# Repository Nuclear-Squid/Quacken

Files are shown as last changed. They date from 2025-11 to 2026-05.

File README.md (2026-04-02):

# Quacken

Libre, ergonomic, *polymorphic*: a single PCB for many possible layouts.

[3×6, 3×5, hummingbird, and everything in between](https://html-preview.github.io/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).

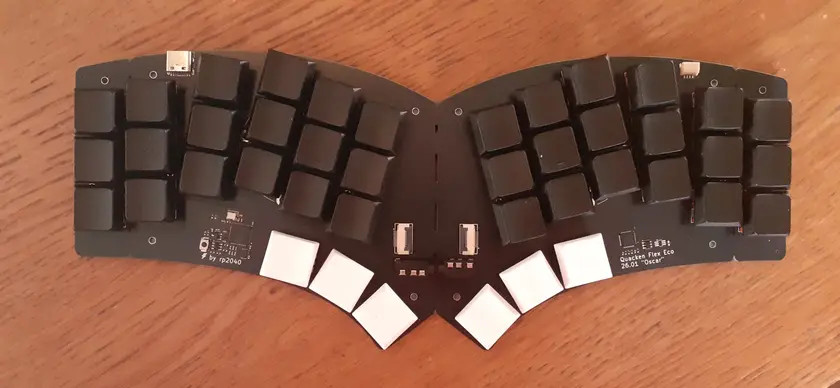
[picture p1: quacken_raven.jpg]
Quacken Flex, unibody Raven, 42 keys

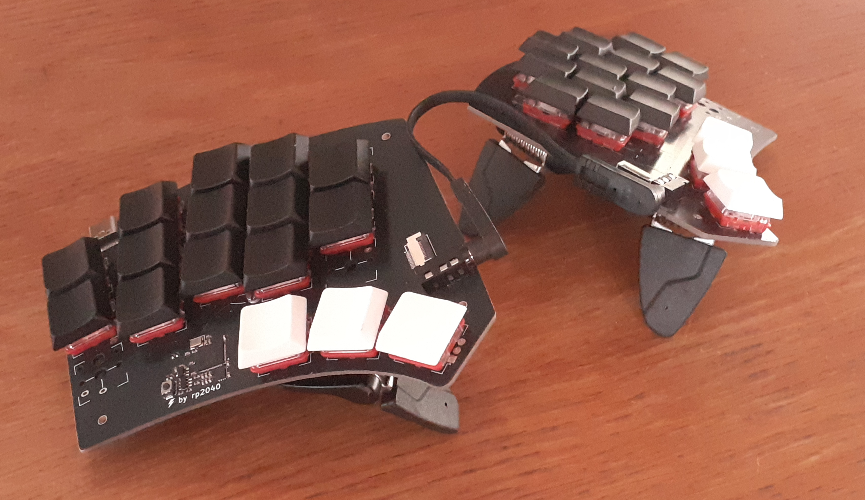
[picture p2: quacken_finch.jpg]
Quacken Flex, split Finch, 32 keys


## Roadmap

- [x] **Quacken Zero**: unibody
  - [x] first batch with a Pro Micro slot, to experiment geometry and design choices
  - [ ] next batches with an onboard nRF52840 (Bluetooth LE) and the updated geometry

- [x] **Quacken Flex**: unibody by default, splittable by choice
  - [x] onboard RP2040 (left) and I/O expander (right)
  - [x] splittable in two (I²C communication over a TRRS cable)
  - [x] splittable outer columns
  - [ ] hotswap sockets
  - [ ] optional Circle Trackpad
  - [x] optional rotary encoders

- [ ] **Marie-Quackenette**: split and wireless variant of the Quacken Flex.

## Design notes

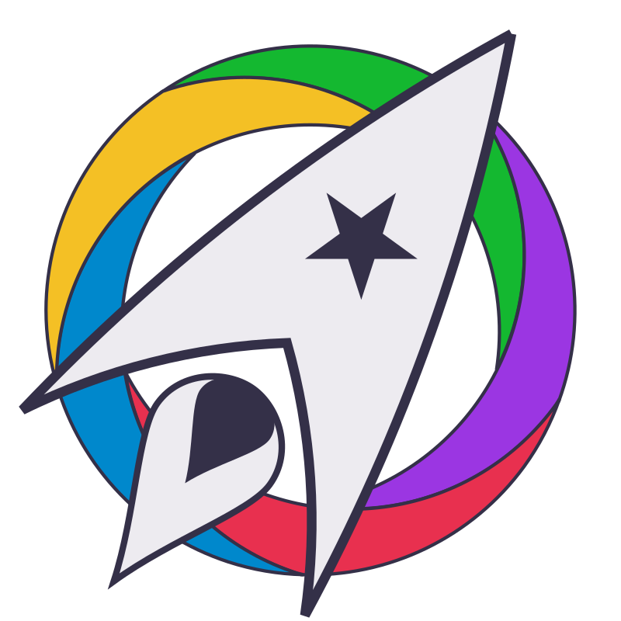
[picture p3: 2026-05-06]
flex/silkscreen/ergol.png

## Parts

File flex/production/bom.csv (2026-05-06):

Designator | Footprint | Quantity | Value | LCSC Part #
C1, C2 | 0402 | 2 | 15p | C1548
C10, C12, C13, C14, C16, C18, C19, C20, C3, C4, C7, C9 | 0402 | 12 | 100n | C1525
C15, C17, C5, C6, C8 | 0402 | 5 | 1u | C52923
J1, J2 | Cirque | 2 | CIRQUE_Left, CIRQUE_Right | C2911838
J3 | USB_C_Receptacle_HRO_TYPE-C-31-M-12 | 1 | USB_C_Receptacle_USB2.0_16P | C165948
J4 | JST_SH_SM04B-SRSS-TB_1x04-1MP_P1.00mm_Horizontal | 1 | Qwiic | C160404
R1, R5 | 0402 | 2 | 1k | C11702
R10, R9 | 0402 | 2 | 4.7k | C25900
R11, R2, R7, R8 | 0402 | 4 | 2.2k | C25879
R12, R13 | 0402 | 2 | 5.1k | C25905
R3, R4 | 0402 | 2 | 27 | C2909343
R6 | 0402 | 1 | 10k | C25744
TRRS1, TRRS2 | TRRS-PJ-320A-dual | 2 | AudioJack4 | C2884926
SMDSW1 | SW_SPST_TS-1088-xR020 | 1 | TS-1088R-02026 | C720477
U1 | Winbond_USON-8-1EP_3x2mm_P0.5mm_EP0.2x1.6mm | 1 | W25Q16JVUX | C2843335
U2 | QFN-56-1EP_7x7mm_P0.4mm_EP3.2x3.2mm | 1 | RP2040 | C2040
U3 | PCAL6524HEHZ | 1 | PCAL6524HEAZ | C3000497
U4 | SOT-23-3 | 1 | XC6206PxxxMR | C5446
U5, U6 | SOT-23-6 | 2 | SRV05-4 | C2836319
Y1 | Crystal_SMD_3225-4Pin_3.2x2.5mm | 1 | 12MHz 10pF | C91749

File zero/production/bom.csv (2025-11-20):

Designator | Footprint | Quantity | Value | LCSC Part #
D1, D10, D11, D12, D13, D14, D15, D16, D17, D18, D19, D2, D20, D21, D22, D23, D24, D25, D26, D27, D28, D29, D3, D30, D31, D32, D33, D34, D35, D36, D37, D38, D39, D4, D40, D41, D42, D5, D6, D7, D8, D9 | D_SOD-323 | 42

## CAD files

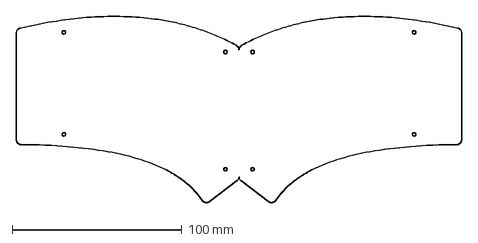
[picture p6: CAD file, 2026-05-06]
freecad/quacken_flex-Mono 3_6.dxf
262.0 x 109.6 mm

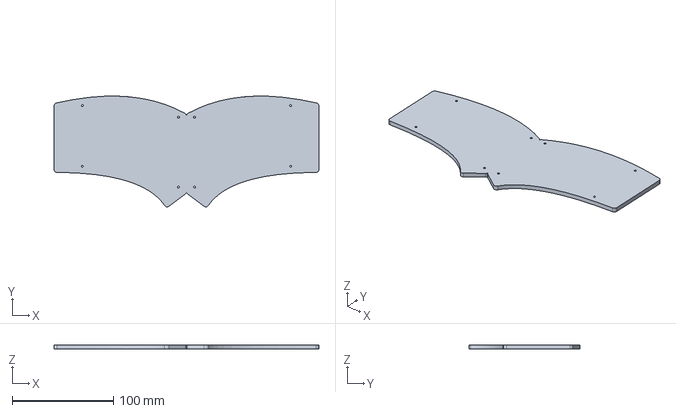
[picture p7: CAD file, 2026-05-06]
quacken_flex.FCStd
262.0 x 109.5 x 4.00 mm

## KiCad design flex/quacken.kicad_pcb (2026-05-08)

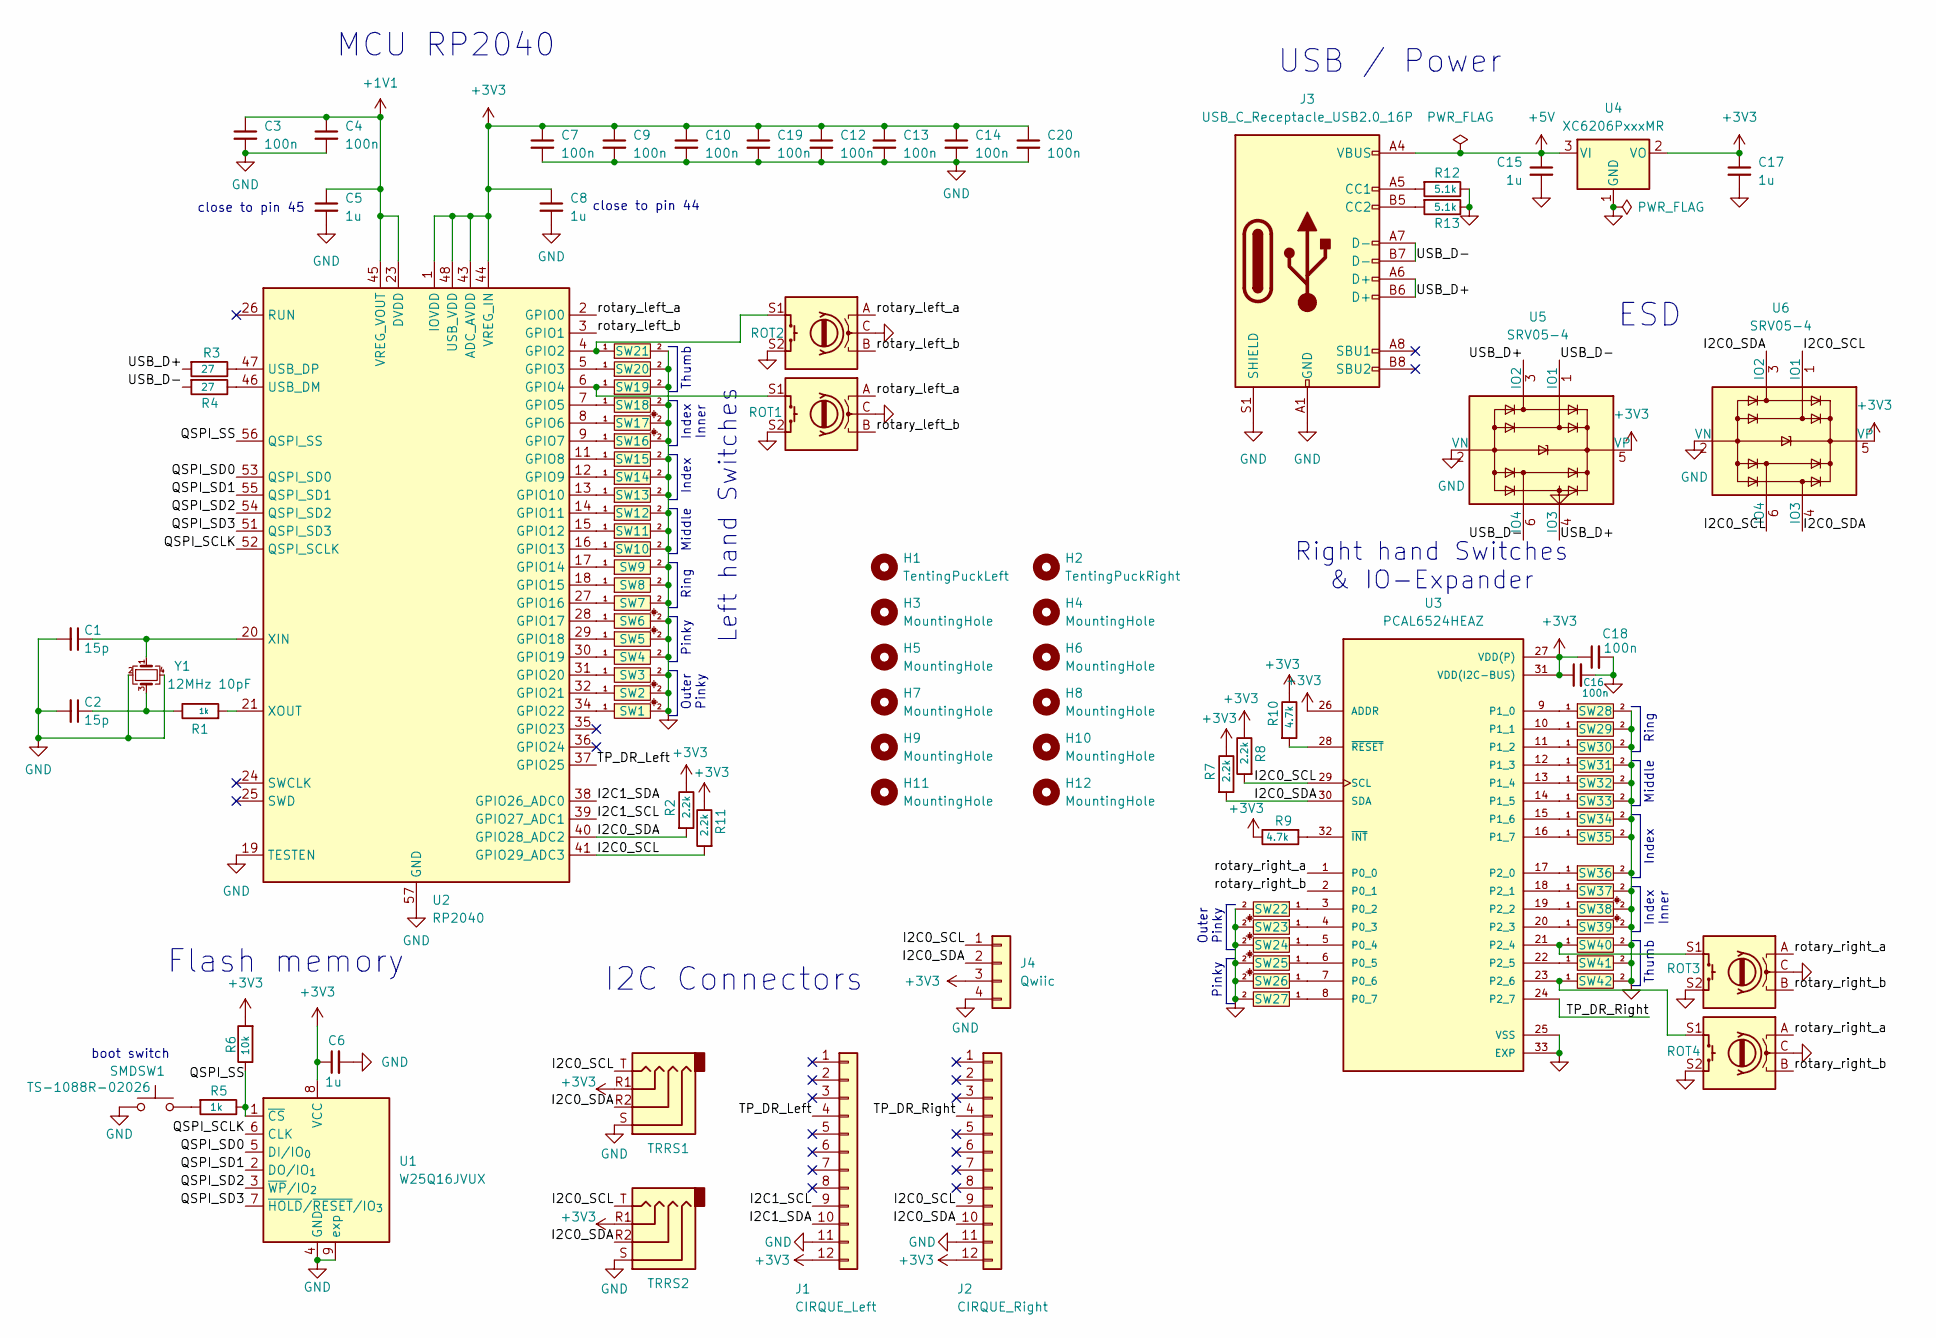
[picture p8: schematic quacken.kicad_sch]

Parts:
C1, C2: 15p; C_0402_1005Metric
C3, C4, C7, C9, C10, C12, C13, C14, C16, C18, C19, C20: 100n; C_0402_1005Metric
C5, C6, C8, C15, C17: 1u; C_0402_1005Metric
H1: TentingPuckLeft; TentingPuck
H2: TentingPuckRight; TentingPuck
H3, H4, H5, H6, H7, H8, H9, H10, H11, H12: MountingHole; MountingHole_2.2mm_M2_DIN965_Pad_TopOnly
J1: CIRQUE_Left; Cirque; JLCPCB Part # C2911838
J2: CIRQUE_Right; Cirque; JLCPCB Part # C2911838
J3: USB_C_Receptacle_USB2.0_16P; USB_C_Receptacle_HRO_TYPE-C-31-M-12; JLCPCB Part # C165948
J4: Qwiic; JST_SH_SM04B-SRSS-TB_1x04-1MP_P1.00mm_Horizontal
R1, R5: 1k; R_0402_1005Metric; JLCPCB Part # C11702
R2, R7, R8, R11: 2.2k; R_0402_1005Metric; JLCPCB Part # C25768
R3, R4: 27; R_0402_1005Metric
R6: 10k; R_0402_1005Metric; JLCPCB Part # C25744
R9, R10: 4.7k; R_0402_1005Metric; JLCPCB Part # C25768
R12, R13: 5.1k; R_0402_1005Metric; JLCPCB Part # C25905
ROT1, ROT2, ROT3, ROT4: RotaryEncoder_Switch; rotary_encoder
SMDSW1: TS-1088R-02026; SW_SPST_TS-1088-xR020; JLCPCB Part # C720477
SW1, SW2, SW5, SW6, SW16, SW17, SW23, SW24, SW25, SW26, SW38, SW39: Choc_Switch_Median
SW3, SW4, SW7, SW8, SW9, SW10, SW11, SW12, SW13, SW14, SW15, SW18, SW19, SW20, SW21, SW22, SW27, SW28, SW29, SW30, SW31, SW32, SW33, SW34, SW35, SW36, SW37, SW40, SW41, SW42: Choc_Switch
TRRS1, TRRS2: AudioJack4; TRRS-PJ-320A-dual; JLCPCB Part # C12569
U1: W25Q16JVUX; Winbond_USON-8-1EP_3x2mm_P0.5mm_EP0.2x1.6mm; JLCPCB Part # C2843335
U2: RP2040; QFN-56-1EP_7x7mm_P0.4mm_EP3.2x3.2mm; JLCPCB Part # C2040
U3: PCAL6524HEAZ; PCAL6524HEHZ; JLCPCB Part # C3000497
U4: XC6206PxxxMR; SOT-23-3; JLCPCB Part # C5446
U5, U6: SRV05-4; SOT-23-6; JLCPCB Part # C2836319
Y1: 12MHz 10pF; Crystal_SMD_3225-4Pin_3.2x2.5mm; MFR.Part # C20625731; JLCPCB Part # C91749

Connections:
+1V1: C3.1, C4.1, C5.1, U2.23 (DVDD), U2.45 (VREG_VOUT), U2.50 (DVDD)
+3V3: C6.1, C7.1, C8.1, C9.1, C10.1, C12.1, C13.1, C14.1, C16.1, C17.1, C18.1, C19.1, C20.1, J1.12, J2.12, J4.3, R2.1, R6.2, R7.1, R8.1, R9.1, R10.1, R11.1, TRRS1.R1, TRRS2.R1, U1.8 (VCC), U2.1 (IOVDD), U2.10 (IOVDD), U2.22 (IOVDD), U2.33 (IOVDD), U2.42 (IOVDD), U2.43 (ADC_AVDD), U2.44 (VREG_IN), U2.48 (USB_VDD), U2.49 (IOVDD), U3.26 (ADDR), U3.27 (VDD(P)), U3.31 (VDD(I2C-BUS)), U4.2 (VO), U5.5 (VP), U6.5 (VP)
+5V: C15.1, J3.A4 (VBUS), J3.A9 (VBUS), J3.B4 (VBUS), J3.B9 (VBUS), U4.3 (VI)
/I2C0_SCL: J2.9, J4.1, R8.2, R11.2, TRRS1.T, TRRS2.T, U2.41 (GPIO29_ADC3), U3.29 (SCL), U6.1 (IO1), U6.6 (IO4)
/I2C0_SDA: J2.10, J4.2, R2.2, R7.2, TRRS1.R2, TRRS2.R2, U2.40 (GPIO28_ADC2), U3.30 (SDA), U6.3 (IO2), U6.4 (IO3)
/I2C1_SCL: J1.9, U2.39 (GPIO27_ADC1)
/I2C1_SDA: J1.10, U2.38 (GPIO26_ADC0)
/QSPI_SCLK: U1.6 (CLK), U2.52 (QSPI_SCLK)
/QSPI_SD0: U1.5 (DI/IO_{0}), U2.53 (QSPI_SD0)
/QSPI_SD1: U1.2 (DO/IO_{1}), U2.55 (QSPI_SD1)
/QSPI_SD2: U1.3 (~WP/IO_{2}), U2.54 (QSPI_SD2)
/QSPI_SD3: U1.7 (~HOLD/~RESET/IO_{3}), U2.51 (QSPI_SD3)
/QSPI_SS: R5.1, R6.1, U1.1 (~CS), U2.56 (QSPI_SS)
/TP_DR_Left: J1.4, U2.37 (GPIO25)
/TP_DR_Right: J2.4, U3.24 (P2_7)
/USB_D+: J3.A6 (D+), J3.B6 (D+), R3.2, U5.3 (IO2), U5.4 (IO3)
/USB_D-: J3.A7 (D-), J3.B7 (D-), R4.2, U5.1 (IO1), U5.6 (IO4)
/rotary_left_a: ROT1.A, ROT2.A, U2.2 (GPIO0)
/rotary_left_b: ROT1.B, ROT2.B, U2.3 (GPIO1)
/rotary_right_a: ROT3.A, ROT4.A, U3.1 (P0_0)
/rotary_right_b: ROT3.B, ROT4.B, U3.2 (P0_1)
GND: C1.2, C2.2, C3.2, C4.2, C5.2, C6.2, C7.2, C8.2, C9.2, C10.2, C12.2, C13.2, C14.2, C15.2, C16.2, C17.2, C18.2, C19.2, C20.2, J1.11, J2.11, J3.A1 (GND), J3.A12 (GND), J3.B1 (GND), J3.B12 (GND), J3.S1 (SHIELD), J4.4, R12.1, R13.1, ROT1.C, ROT1.S2, ROT2.C, ROT2.S2, ROT3.C, ROT3.S2, ROT4.C, ROT4.S2, SMDSW1.1, SW1.2, SW2.2, SW3.2, SW4.2, SW5.2, SW6.2, SW7.2, SW8.2, SW9.2, SW10.2, SW11.2, SW12.2, SW13.2, SW14.2, SW15.2, SW16.2, SW17.2, SW18.2, SW19.2, SW20.2, SW21.2, SW22.2, SW23.2, SW24.2, SW25.2, SW26.2, SW27.2, SW28.2, SW29.2, SW30.2, SW31.2, SW32.2, SW33.2, SW34.2, SW35.2, SW36.2, SW37.2, SW38.2, SW39.2, SW40.2, SW41.2, SW42.2, TRRS1.S, TRRS2.S, U1.4 (GND), U1.9 (exp), U2.19 (TESTEN), U2.57 (GND), U3.25 (VSS), U3.33 (EXP), U4.1 (GND), U5.2 (VN), U6.2 (VN), Y1.2, Y1.4
unnamed: C2.1, R1.1, Y1.3
unnamed: J3.A5 (CC1), R12.2
unnamed: J3.B5 (CC2), R13.2
unnamed: R5.2, SMDSW1.2
unnamed: ROT2.S1, SW21.1, U2.4 (GPIO2)
unnamed: SW20.1, U2.5 (GPIO3)
unnamed: ROT1.S1, SW19.1, U2.6 (GPIO4)
unnamed: SW18.1, U2.7 (GPIO5)
unnamed: SW17.1, U2.8 (GPIO6)
unnamed: SW16.1, U2.9 (GPIO7)
unnamed: SW15.1, U2.11 (GPIO8)
unnamed: SW14.1, U2.12 (GPIO9)
unnamed: SW13.1, U2.13 (GPIO10)
unnamed: SW12.1, U2.14 (GPIO11)
unnamed: SW11.1, U2.15 (GPIO12)
unnamed: SW10.1, U2.16 (GPIO13)
unnamed: SW9.1, U2.17 (GPIO14)
unnamed: SW8.1, U2.18 (GPIO15)
unnamed: SW7.1, U2.27 (GPIO16)
unnamed: SW6.1, U2.28 (GPIO17)
unnamed: SW5.1, U2.29 (GPIO18)
unnamed: SW4.1, U2.30 (GPIO19)
unnamed: SW3.1, U2.31 (GPIO20)
unnamed: SW2.1, U2.32 (GPIO21)
unnamed: SW1.1, U2.34 (GPIO22)
unnamed: R4.1, U2.46 (USB_DM)
unnamed: R3.1, U2.47 (USB_DP)
unnamed: C1.1, U2.20 (XIN), Y1.1
unnamed: R1.2, U2.21 (XOUT)
unnamed: SW22.1, U3.3 (P0_2)
unnamed: SW23.1, U3.4 (P0_3)
unnamed: SW24.1, U3.5 (P0_4)
unnamed: SW25.1, U3.6 (P0_5)
unnamed: SW26.1, U3.7 (P0_6)
unnamed: SW27.1, U3.8 (P0_7)
unnamed: SW28.1, U3.9 (P1_0)
unnamed: SW29.1, U3.10 (P1_1)
unnamed: SW30.1, U3.11 (P1_2)
unnamed: SW31.1, U3.12 (P1_3)
unnamed: SW32.1, U3.13 (P1_4)
unnamed: SW33.1, U3.14 (P1_5)
unnamed: SW34.1, U3.15 (P1_6)
unnamed: SW35.1, U3.16 (P1_7)
unnamed: SW36.1, U3.17 (P2_0)
unnamed: SW37.1, U3.18 (P2_1)
unnamed: SW38.1, U3.19 (P2_2)
unnamed: SW39.1, U3.20 (P2_3)
unnamed: ROT3.S1, SW40.1, U3.21 (P2_4)
unnamed: SW41.1, U3.22 (P2_5)
unnamed: ROT4.S1, SW42.1, U3.23 (P2_6)
unnamed: R9.2, U3.32 (~INT)
unnamed: R10.2, U3.28 (~RESET)

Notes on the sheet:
close to pin 45
Flash memory
USB / Power
Middle
Index Inner
Index
Left hand Switches
MCU RP2040
Ring
Outer Pinky
I2C Connectors
close to pin 44
Thumb
Pinky
ESD
boot switch
Right hand Switches & IO-Expander

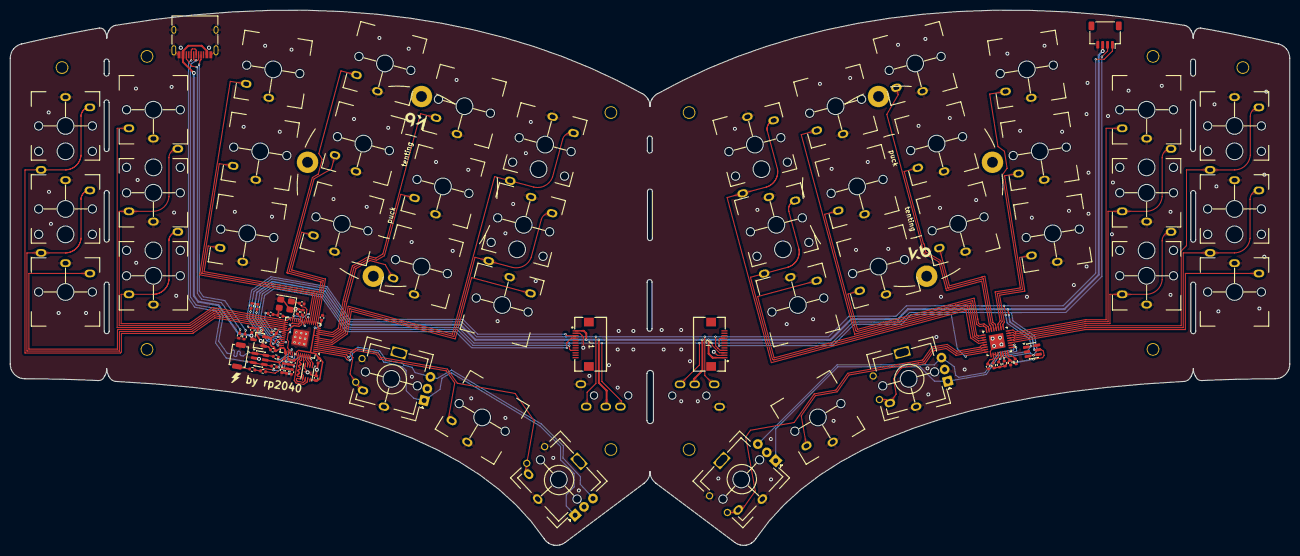
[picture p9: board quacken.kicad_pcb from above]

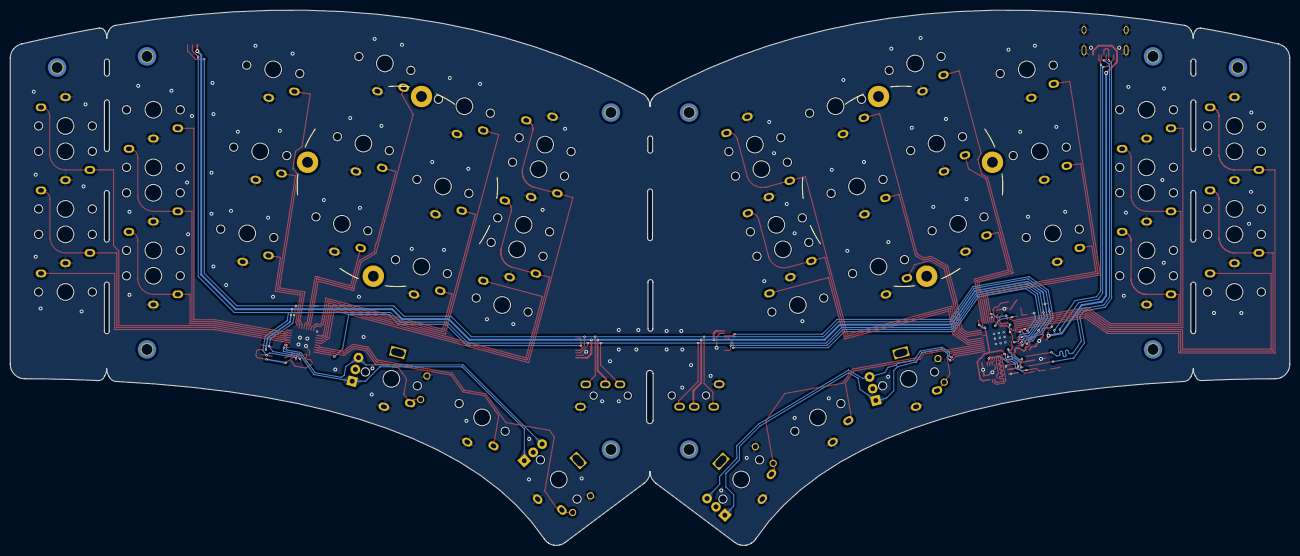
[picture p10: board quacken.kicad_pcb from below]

Board: 2 copper layers, 262.0 x 109.6 mm, 104 parts (10 on the bottom side), 74 nets.

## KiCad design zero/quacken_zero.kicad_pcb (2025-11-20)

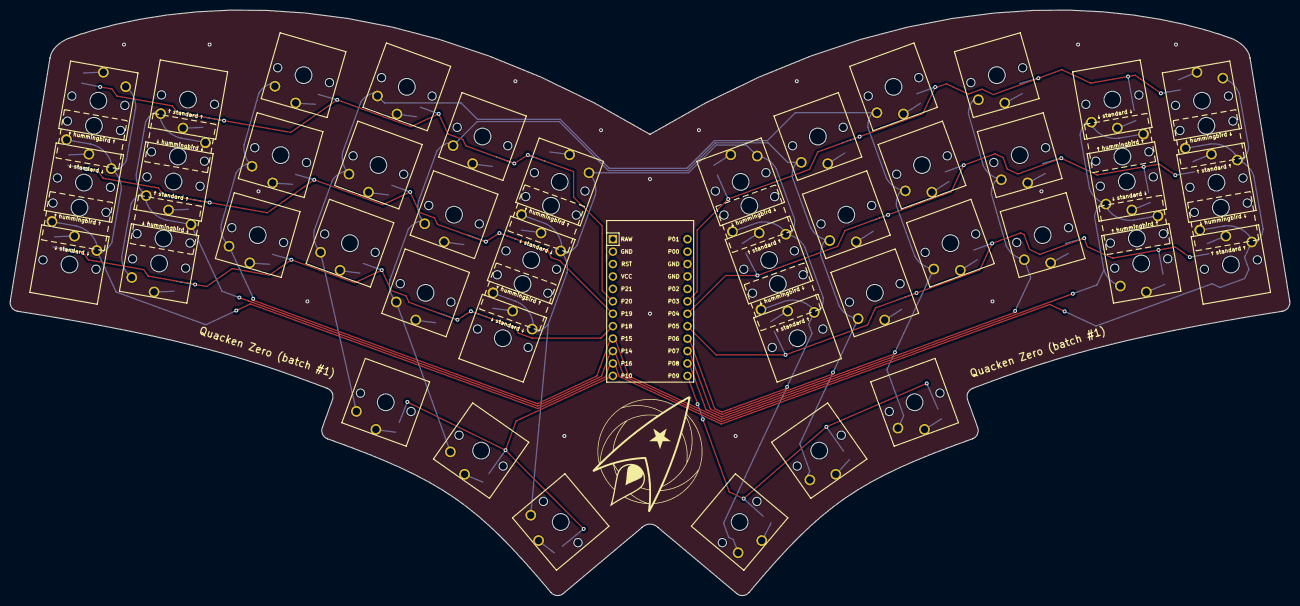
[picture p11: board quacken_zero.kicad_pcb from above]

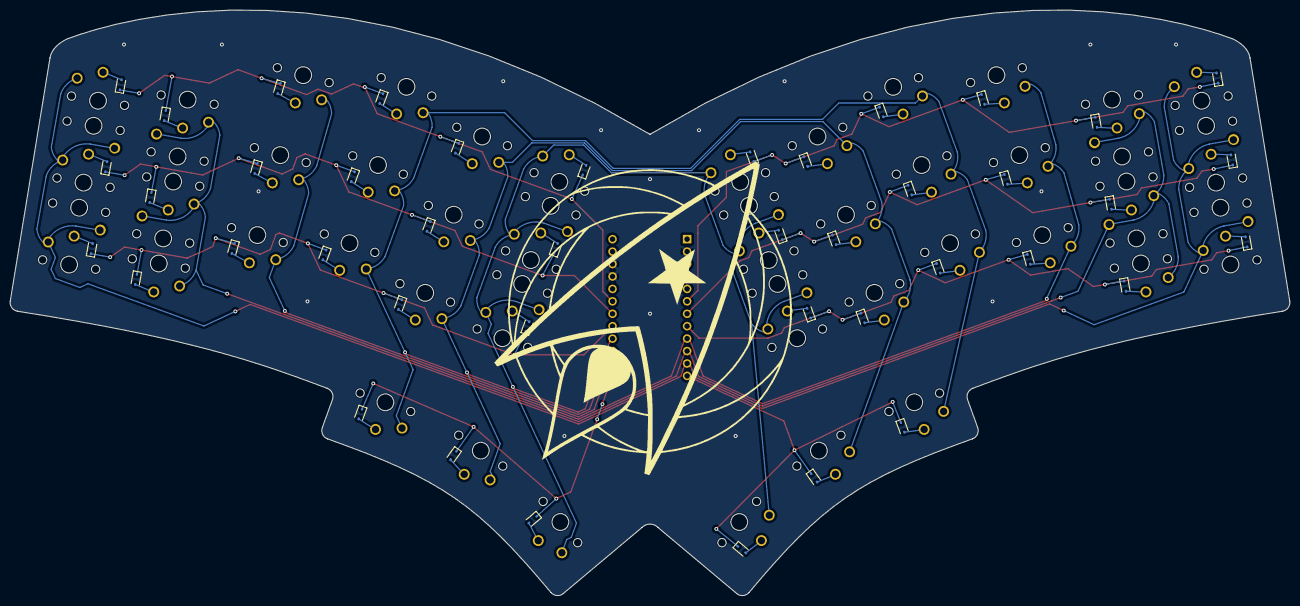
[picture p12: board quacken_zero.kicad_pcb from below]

Board: 2 copper layers, 261.5 x 119.6 mm, 85 parts (42 on the bottom side), 57 nets.

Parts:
D1, D2, D3, D4, D5, D6, D7, D8, D9, D10, D11, D12, D13, D14, D15, D16, D17, D18, D19, D20, D21, D22, D23, D24, D25, D26, D27, D28, D29, D30, D31, D32, D33, D34, D35, D36, D37, D38, D39, D40, D41, D42: D_SOD-323
MCU1: ProMicro
S1, S2, S3, S4, S5, S6, S7, S8, S9, S10, S11, S12, S13, S14, S15, S16, S17, S18, S19, S20, S21, S22, S23, S24, S25, S26, S27, S28, S29, S30, S31, S32, S33, S34, S35, S36, S37, S38, S39, S40, S41, S42: PG1350

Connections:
GND: MCU1.2, MCU1.15, MCU1.16
P3: D18.1, D21.1, D24.1, D27.1, D39.1, D42.1, MCU1.18
P4: D17.1, D20.1, D23.1, D26.1, D38.1, D41.1, MCU1.19
P5: D16.1, D19.1, D22.1, D25.1, D37.1, D40.1, MCU1.20
P6: MCU1.21, S15.1, S30.1, S34.1, S34.3, S35.1, S35.3, S36.1, S40.1, S40.3, S41.1, S41.3, S42.1
P7: MCU1.22, S10.1, S11.1, S12.1, S14.1, S25.1, S26.1, S27.1, S29.1
P8: MCU1.23, S7.1, S8.1, S9.1, S13.1, S22.1, S23.1, S24.1, S28.1
P9: D28.1, D29.1, D30.1, MCU1.24
P10: D13.1, D14.1, D15.1, MCU1.12
P14: MCU1.10, S1.1, S2.1, S2.3, S3.1, S3.3, S16.1, S17.1, S17.3, S18.1, S18.3
P15: MCU1.9, S4.1, S5.1, S6.1, S19.1, S20.1, S21.1
P16: MCU1.11, S31.1, S31.3, S32.1, S32.3, S33.1, S37.1, S37.3, S38.1, S38.3, S39.1
P18: D1.1, D4.1, D7.1, D10.1, D31.1, D34.1, MCU1.8
P19: D2.1, D5.1, D8.1, D11.1, D32.1, D35.1, MCU1.7
P20: D3.1, D6.1, D9.1, D12.1, D33.1, D36.1, MCU1.6
comfy_default: D14.2, S14.2
index_bottom: D10.2, S10.2
index_home: D11.2, S11.2
index_top: D12.2, S12.2
inner_bottom: D34.2, S34.2
inner_home: D35.2, S35.2
inner_top: D36.2, S36.2
middle_bottom: D7.2, S7.2
middle_home: D8.2, S8.2
middle_top: D9.2, S9.2
mirror_comfy_default: D29.2, S29.2
mirror_index_bottom: D25.2, S25.2
mirror_index_home: D26.2, S26.2
mirror_index_top: D27.2, S27.2
mirror_inner_bottom: D40.2, S40.2
mirror_inner_home: D41.2, S41.2
mirror_inner_top: D42.2, S42.2
mirror_middle_bottom: D22.2, S22.2
mirror_middle_home: D23.2, S23.2
mirror_middle_top: D24.2, S24.2
mirror_outer_bottom: D37.2, S37.2
mirror_outer_home: D38.2, S38.2
mirror_outer_top: D39.2, S39.2
mirror_pinky_bottom: D16.2, S16.2
mirror_pinky_home: D17.2, S17.2
mirror_pinky_top: D18.2, S18.2
mirror_reachy_default: D30.2, S30.2
mirror_ring_bottom: D19.2, S19.2
mirror_ring_home: D20.2, S20.2
mirror_ring_top: D21.2, S21.2
mirror_tucky_default: D28.2, S28.2
outer_bottom: D31.2, S31.2
outer_home: D32.2, S32.2
outer_top: D33.2, S33.2
pinky_bottom: D1.2, S1.2
pinky_home: D2.2, S2.2
pinky_top: D3.2, S3.2
reachy_default: D15.2, S15.2
ring_bottom: D4.2, S4.2
ring_home: D5.2, S5.2
ring_top: D6.2, S6.2
tucky_default: D13.2, S13.2

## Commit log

2025-07-23 Holy shit this time it’s not the GH action’s fault?
2025-11-20 Flex 25.10
    Cleaner hierarchy
    Moved ergogen stuff to it’s own folder
    Even simpler hierarchy
    Moved production folder
    [board.dxf, bom.csv, bom_1.csv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]
2026-05-03 flex 25.11 (#11)
    [bom.csv, bom_1.csv, designators.csv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]
2026-05-06 flex 25.12 (#12)
    [bom.csv, designators.csv, positions.csv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]
2026-05-06 flex 26.01 (#15)
    [bom.csv, designators.csv, positions.csv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]
2026-05-08 Fix PCB outline (#16)
    [quacken.kicad_pcb]
